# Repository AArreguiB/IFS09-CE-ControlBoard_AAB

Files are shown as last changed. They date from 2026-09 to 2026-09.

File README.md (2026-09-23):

isc-full-primary

# IFSXX-[DPT]_[PCB/PURPOSE]

Embedded firmware for the **[PCB/PURPOSE]** of the IFSXX, developed on XXXXXXXXX with XXXXXXXXX.

---

## Getting started

1. Create a GitHub account if you don't have one yet.
2. Download and install [GitHub Desktop](https://desktop.github.com/) (beginner) or [Git CLI](https://git-scm.com/book/en/v2/Getting-Started-Installing-Git) (advanced).

   - If this is your first time using GitHub Desktop, make sure to read the [User Manual](https://help.github.com/desktop/guides/).
   - If this is your first time using Git, start with a tutorial. There are many available online:
     - [Git Tutorial](https://git-scm.com/docs/gittutorial)
     - [Atlassian Git Tutorial](https://www.atlassian.com/git/tutorials/)
   - Keep a copy of [GitHub's Git Cheat Sheet](https://services.github.com/kit/downloads/github-git-cheat-sheet.pdf) handy as a reference.

3. Clone this repository to your machine (update these links!!):
   - SSH: `git@github.com:isc-fs/IFSXX-[DPT]_[PCB/PURPOSE].git`
   - HTTPS: `https://github.com/isc-fs/IFSXX-[DPT]_[PCB/PURPOSE].git`

---

## How we work with this repository

### Main branches

The repository has two permanent branches:

**`main`** is the production branch. It contains only validated code that can be flashed onto the car. Never work directly on it.

**`dev`** is the development branch. It is the integration point where everyone's work comes together. Never work directly on it either — all changes arrive through a feature branch.

```
main  ──────────────────●──────────────────────●──▶  (validated releases only)
                        ↑                      ↑
dev   ──────●───●───●───●───●───●───●───●───●──●──▶  (continuous integration)
            ↑   ↑       ↑   ↑   ↑       ↑   ↑
          feat/1 fix/1 feat/2 fix/2   feat/3 fix/3
```

### Feature branches

All work — whether a new feature or a bug fix — is done on a **feature branch** created from `dev`. When the work is ready, a Pull Request is opened toward `dev`, reviewed, merged, and the branch is deleted.

There are two branch types, each with its own independent numeric counter:

```
feat/<n>   →  new functionality  (feat/1, feat/2, feat/3 ...)
fix/<n>    →  bug fix            (fix/1,  fix/2,  fix/3  ...)
```

The `feat` and `fix` counters are independent: `feat/2` and `fix/2` can exist at the same time with no conflict.

### Tracking branch history

Feature branches are deleted after merging to keep the repository clean. The history of each branch is preserved in **GitHub Issues**.

Every branch has one associated issue. The issue carries a **label** (`feat` or `fix`) and its title includes the branch number, for example: `[feat/3] Add CAN broadcast for mission state`. When the branch is merged and deleted, the issue is closed — becoming a permanent record of all the work done.

To see which branches are currently active: filter issues by label and status `open`.
To browse the full history: filter by label and status `closed`.
The number for the next branch of each type is the last closed issue of that type plus one.

> Example: if the last closed issue with label `feat` is `[feat/4] ...`, the next feature branch will be `feat/5`.

---

## Automation

The repository includes a GitHub Actions workflow that manages tracking issues automatically. No setup is required — it works for every developer as soon as they create a branch.

### Automatic issue creation

When a `feat/*` or `fix/*` branch is pushed to GitHub, the workflow automatically opens an issue with:

- The corresponding `[feat/N]` or `[fix/N]` title
- The correct label (`feat` or `fix`)
- A template with sections for describing the work and adding notes
- The name of the developer who created the branch

### Wrong number warning

If the branch number is not the next expected one (either too low or too high), the issue will display a warning indicating the correct number and asking the developer to delete and recreate the branch with the right name.

### Auto-fill description from first commit

When the developer makes their first commit and pushes it, the workflow automatically updates the *"What does this branch do?"* section of the issue with that commit message.

- If the developer manually edits the issue before pushing their first commit, the workflow will not overwrite the description.
- The description is only updated once — subsequent commits do not modify the issue.

---

## Step-by-step workflow

### 1. Create the branch

```bash
# Make sure you are on an up-to-date dev
git checkout dev
git pull origin dev

# Create your branch using the next available number for its type
# (last closed issue of that type + 1)
git checkout -b feat/5    # or fix/3, depending on that type's counter
```

> To find the right number: go to **Issues → filter by label `feat` or `fix` → sort by newest** and read the last number.

### 2. Push the branch

```bash
git push origin feat/5
```

The tracking issue will be opened automatically on GitHub within seconds.

### 3. Work and commit

```bash
# Make your changes and commit with a clear, descriptive message
git add .
git commit -m "short description of what this commit does"

# Push the changes
git push origin feat/5
```

The message of your **first commit** will be used to automatically fill in the issue description.

### 4. Open a Pull Request

When the work is ready, open a Pull Request on GitHub from your branch toward `dev`. In the PR description write `Closes #<issue-number>` so the issue closes automatically when the PR is merged.

Before requesting a review, check that:
- The code compiles with no errors or warnings
- You have tested the change on the bench if applicable
- The PR targets `dev`, not `main`

### 5. Review and merge

Another team member will review the PR. Once approved, it is merged into `dev` and the branch is deleted. The issue will be closed as a permanent record.

### 6. Merging into main

When `dev` holds a set of validated changes that are ready for the car, a responsible team member opens a Pull Request from `dev` into `main`. This only happens after full firmware validation (HIL/bench).

---

*ISC Racing Team — IFS08 Driverless*

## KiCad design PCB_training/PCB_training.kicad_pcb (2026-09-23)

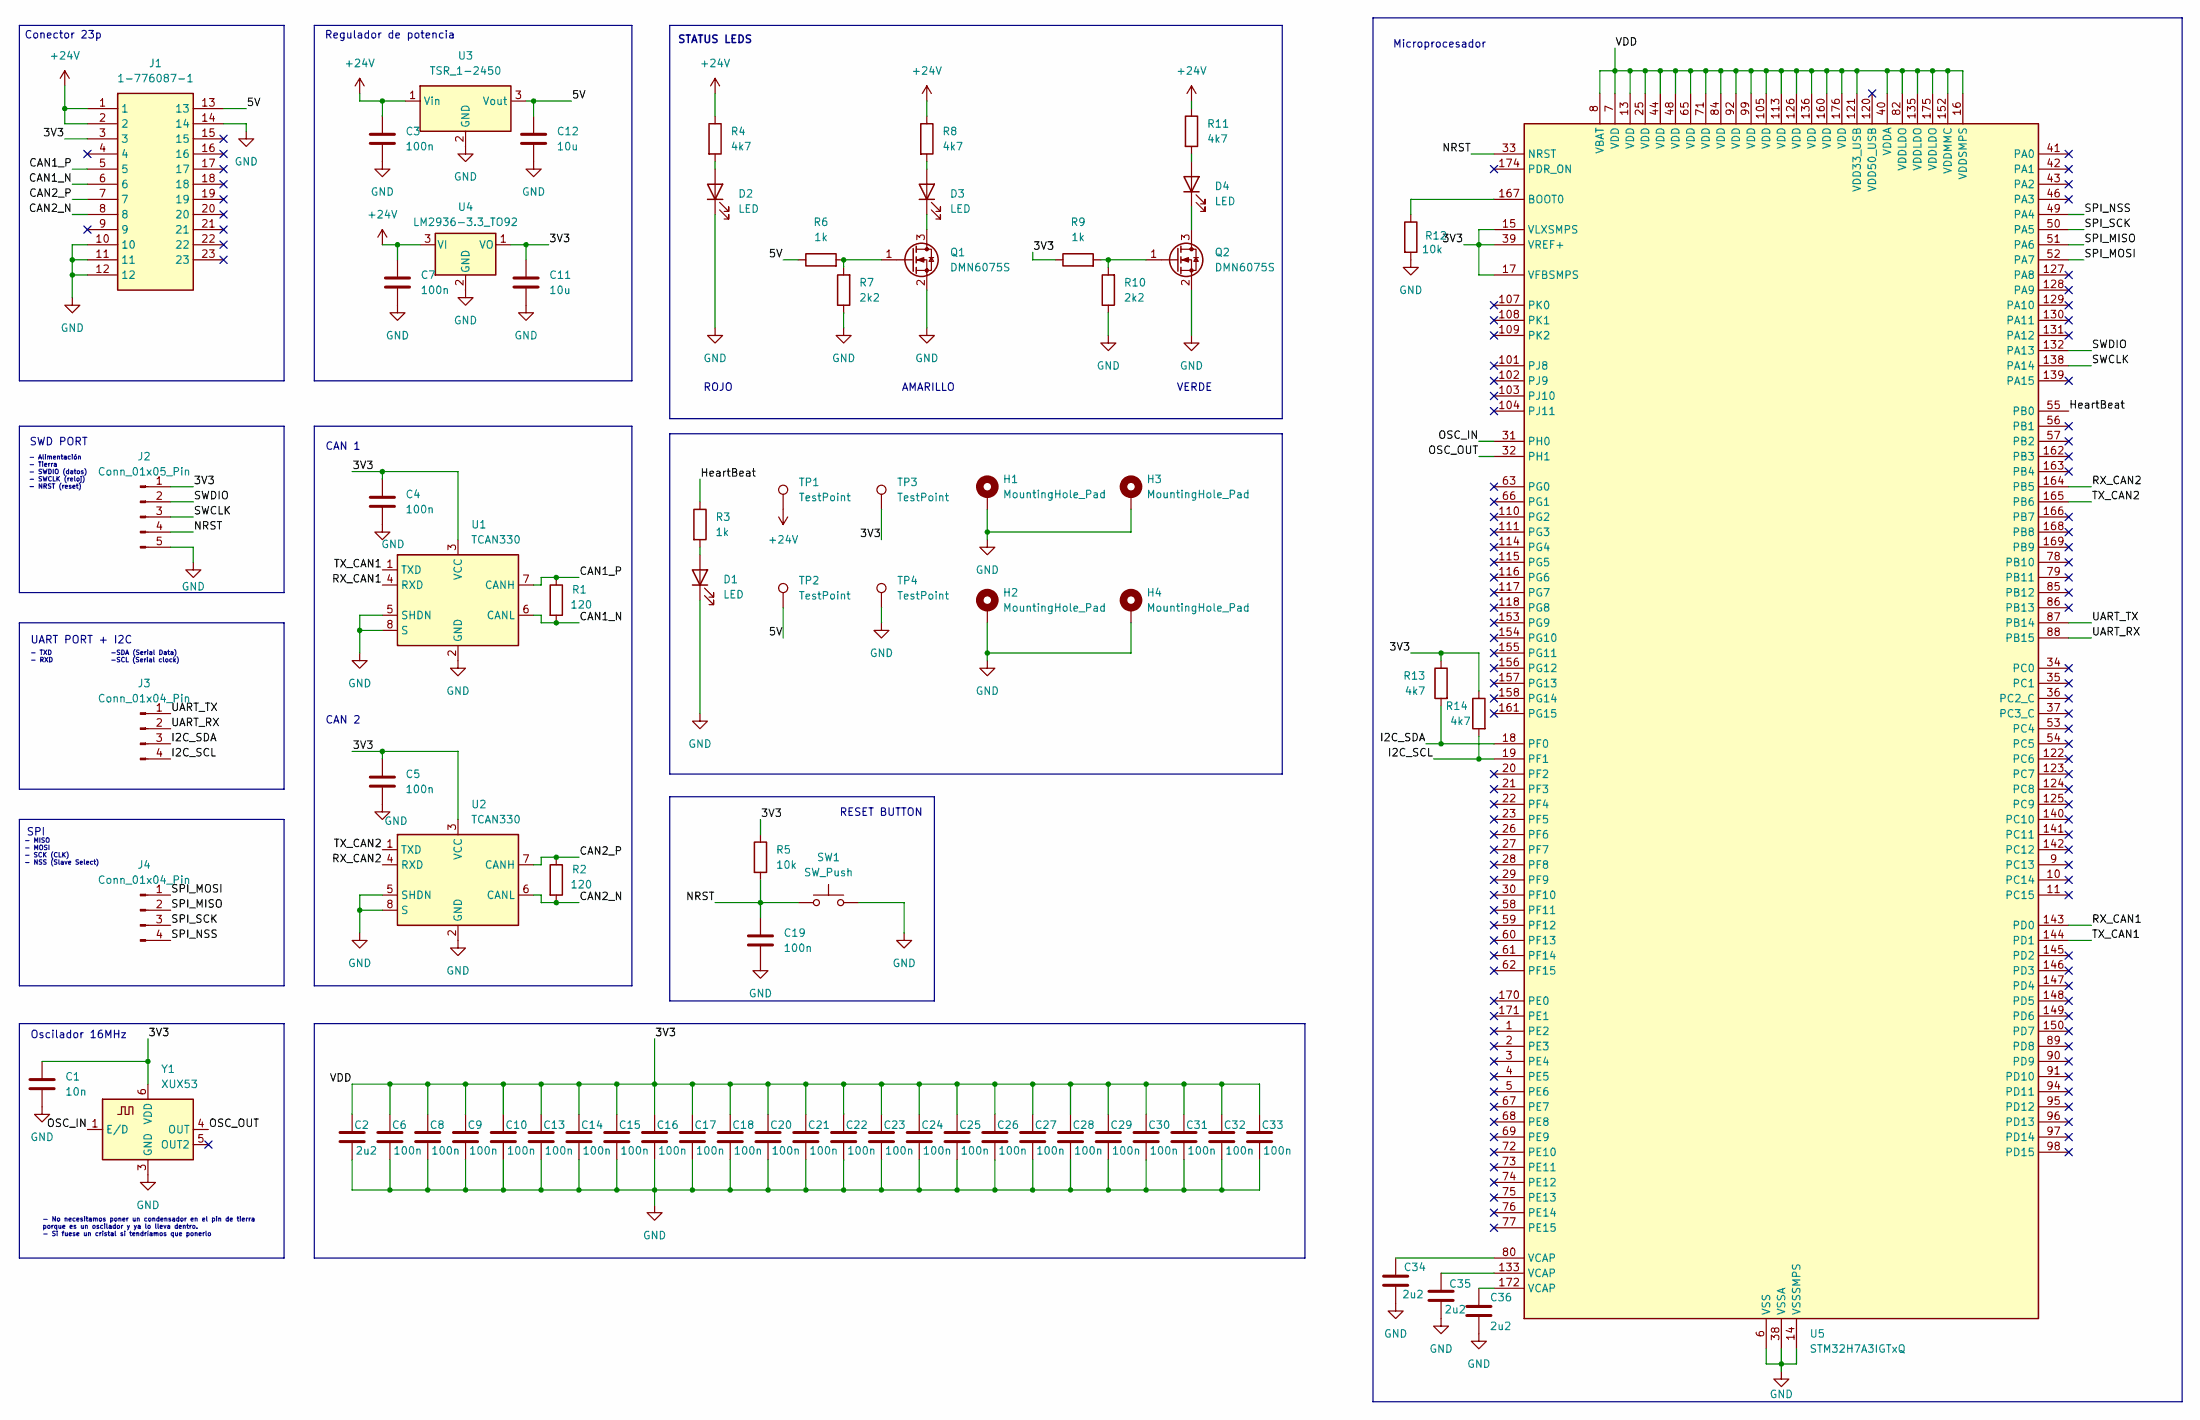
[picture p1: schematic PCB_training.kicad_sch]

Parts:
C1: 10n; C_0805_2012Metric_Pad1.18x1.45mm_HandSolder
C2, C34, C35, C36: 2u2; C_0805_2012Metric_Pad1.18x1.45mm_HandSolder
C3, C4, C5, C6, C7, C8, C9, C10, C13, C14, C15, C16, C17, C18, C19, C20, C21, C22, C23, C24, C25, C26, C27, C28, C29, C30, C31, C32, C33: 100n; C_0805_2012Metric_Pad1.18x1.45mm_HandSolder
C11, C12: 10u; C_0805_2012Metric_Pad1.18x1.45mm_HandSolder
D1, D2, D3, D4: LED; LED_1206_3216Metric_Pad1.42x1.75mm_HandSolder
H1, H2, H3, H4: MountingHole_Pad; MountingHole_3.2mm_M3_Pad
J1: 1-776087-1; 17760871; Mouser Part Number 571-1-776087-1
J2: Conn_01x05_Pin; PinHeader_1x05_P2.54mm_Vertical
J3, J4: Conn_01x04_Pin; PinHeader_1x04_P2.54mm_Vertical
Q1, Q2: DMN6075S; SOT-23
R1, R2: 120; R_0805_2012Metric_Pad1.20x1.40mm_HandSolder
R3, R6, R9: 1k; R_0805_2012Metric_Pad1.20x1.40mm_HandSolder
R4, R8, R11, R13, R14: 4k7; R_0805_2012Metric_Pad1.20x1.40mm_HandSolder
R5, R12: 10k; R_0805_2012Metric_Pad1.20x1.40mm_HandSolder
R7, R10: 2k2; R_0805_2012Metric_Pad1.20x1.40mm_HandSolder
SW1: SW_Push; Panasonic_EVQPUK_EVQPUB
TP1, TP2, TP3, TP4: TestPoint; TestPoint_Pad_D2.0mm
U1, U2: TCAN330; SOIC-8_3.9x4.9mm_P1.27mm
U3: TSR_1-2450; Converter_DCDC_TRACO_TSR-1_THT
U4: LM2936-3.3_TO92; TO-92_Inline
U5: STM32H7A3IGTxQ; LQFP-176_24x24mm_P0.5mm
Y1: XUX53; Oscillator_SMD_IDT_JS6-6_5.0x3.2mm_P1.27mm

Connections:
+24V: C3.1, C7.1, J1.1, J1.2, R4.1, R8.1, R11.1, TP1.1 (1_1), U3.1 (Vin), U4.3 (VI)
/3V3: C1.1, C2.1, C4.1, C5.1, C6.1, C8.1, C9.1, C10.1, C11.1, C13.1, C14.1, C15.1, C16.1, C17.1, C18.1, C20.1, C21.1, C22.1, C23.1, C24.1, C25.1, C26.1, C27.1, C28.1, C29.1, C30.1, C31.1, C32.1, C33.1, J1.3, J2.1, R5.1, R9.1, R13.1, R14.1, TP3.1 (1_1), U1.3 (VCC), U2.3 (VCC), U4.1 (VO), U5.7 (VDD), U5.8 (VBAT), U5.13 (VDD), U5.15 (VLXSMPS), U5.16 (VDDSMPS), U5.17 (VFBSMPS), U5.25 (VDD), U5.39 (VREF+), U5.40 (VDDA), U5.44 (VDD), U5.48 (VDD), U5.65 (VDD), U5.71 (VDD), U5.82 (VDDLDO), U5.84 (VDD), U5.92 (VDD), U5.99 (VDD), U5.105 (VDD), U5.113 (VDD), U5.121 (VDD33_USB), U5.126 (VDD), U5.135 (VDDLDO), U5.136 (VDD), U5.152 (VDDMMC), U5.160 (VDD), U5.175 (VDDLDO), U5.176 (VDD), Y1.6 (VDD)
/5V: C12.1, J1.13, R6.1, TP2.1 (1_1), U3.3 (Vout)
/CAN1_N: J1.6, R1.2, U1.6 (CANL)
/CAN1_P: J1.5, R1.1, U1.7 (CANH)
/CAN2_N: J1.8, R2.2, U2.6 (CANL)
/CAN2_P: J1.7, R2.1, U2.7 (CANH)
/HeartBeat: R3.1, U5.55 (PB0)
/I2C_SCL: J3.4, R14.2, U5.19 (PF1)
/I2C_SDA: J3.3, R13.2, U5.18 (PF0)
/NRST: C19.1, J2.4, R5.2, SW1.1, U5.33 (NRST)
/OSC_IN: U5.31 (PH0), Y1.1 (E/D)
/OSC_OUT: U5.32 (PH1), Y1.4 (OUT)
/RX_CAN1: U1.4 (RXD), U5.143 (PD0)
/RX_CAN2: U2.4 (RXD), U5.164 (PB5)
/SPI_MISO: J4.2, U5.51 (PA6)
/SPI_MOSI: J4.1, U5.52 (PA7)
/SPI_NSS: J4.4, U5.49 (PA4)
/SPI_SCK: J4.3, U5.50 (PA5)
/SWCLK: J2.3, U5.138 (PA14)
/SWDIO: J2.2, U5.132 (PA13)
/TX_CAN1: U1.1 (TXD), U5.144 (PD1)
/TX_CAN2: U2.1 (TXD), U5.165 (PB6)
/UART_RX: J3.2, U5.88 (PB15)
/UART_TX: J3.1, U5.87 (PB14)
GND: C1.2, C2.2, C3.2, C4.2, C5.2, C6.2, C7.2, C8.2, C9.2, C10.2, C11.2, C12.2, C13.2, C14.2, C15.2, C16.2, C17.2, C18.2, C19.2, C20.2, C21.2, C22.2, C23.2, C24.2, C25.2, C26.2, C27.2, C28.2, C29.2, C30.2, C31.2, C32.2, C33.2, C34.2, C35.2, C36.2, D1.1 (K), D2.1 (K), H1.1 (1_1), H2.1 (1_1), H3.1 (1_1), H4.1 (1_1), J1.10, J1.11, J1.12, J1.14, J2.5, Q1.2 (S), Q2.2 (S), R7.1, R10.1, R12.2, SW1.2, TP4.1 (1_1), U1.2 (GND), U1.5 (SHDN), U1.8 (S), U2.2 (GND), U2.5 (SHDN), U2.8 (S), U3.2 (GND), U4.2 (GND), U5.6 (VSS), U5.12 (VSS), U5.14 (VSSSMPS), U5.24 (VSS), U5.38 (VSSA), U5.45 (VSS), U5.47 (VSS), U5.64 (VSS), U5.70 (VSS), U5.81 (VSS), U5.83 (VSS), U5.93 (VSS), U5.100 (VSS), U5.106 (VSS), U5.112 (VSS), U5.119 (VSS), U5.134 (VSS), U5.137 (VSS), U5.151 (VSS), U5.159 (VSS), U5.173 (VSS), Y1.3 (GND)
unnamed: C34.1, U5.80 (VCAP)
unnamed: C35.1, U5.133 (VCAP)
unnamed: C36.1, U5.172 (VCAP)
unnamed: D1.2 (A), R3.2
unnamed: D2.2 (A), R4.2
unnamed: D3.2 (A), R8.2
unnamed: D3.1 (K), Q1.3 (D)
unnamed: D4.2 (A), R11.2
unnamed: D4.1 (K), Q2.3 (D)
unnamed: Q1.1 (G), R6.2, R7.2
unnamed: Q2.1 (G), R9.2, R10.2
unnamed: R12.1, U5.167 (BOOT0)

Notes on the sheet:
Conector 23p
SWD PORT
- TXD - RXD
- Alimentación - Tierra - SWDIO (datos) - SWCLK (reloj) - NRST (reset)
Microprocesador
- MISO - MOSI - SCK (CLK) - NSS (Slave Select)
SPI
ROJO
RESET BUTTON
AMARILLO
-SDA (Serial Data) -SCL (Serial clock)
Oscilador 16MHz
VERDE
Regulador de potencia
CAN 1
UART PORT + I2C
- No necesitamos poner un condensador en el pin de tierra porque es un oscilador y ya lo lleva dentro. - Si fuese un cristal si tendríamos que ponerlo
STATUS LEDS
CAN 2

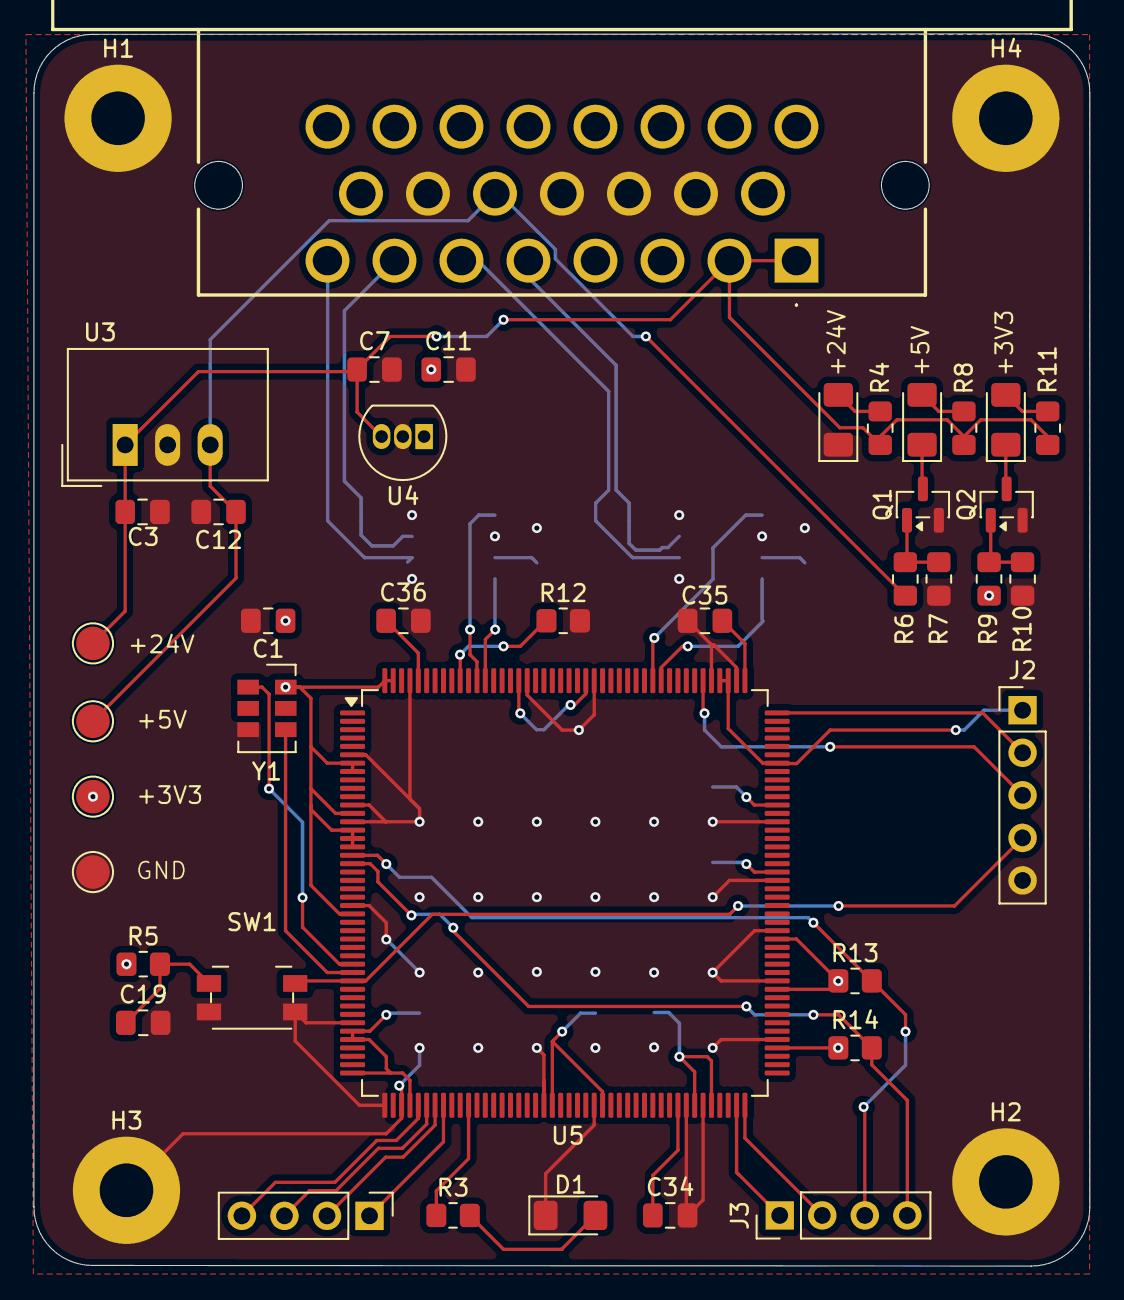
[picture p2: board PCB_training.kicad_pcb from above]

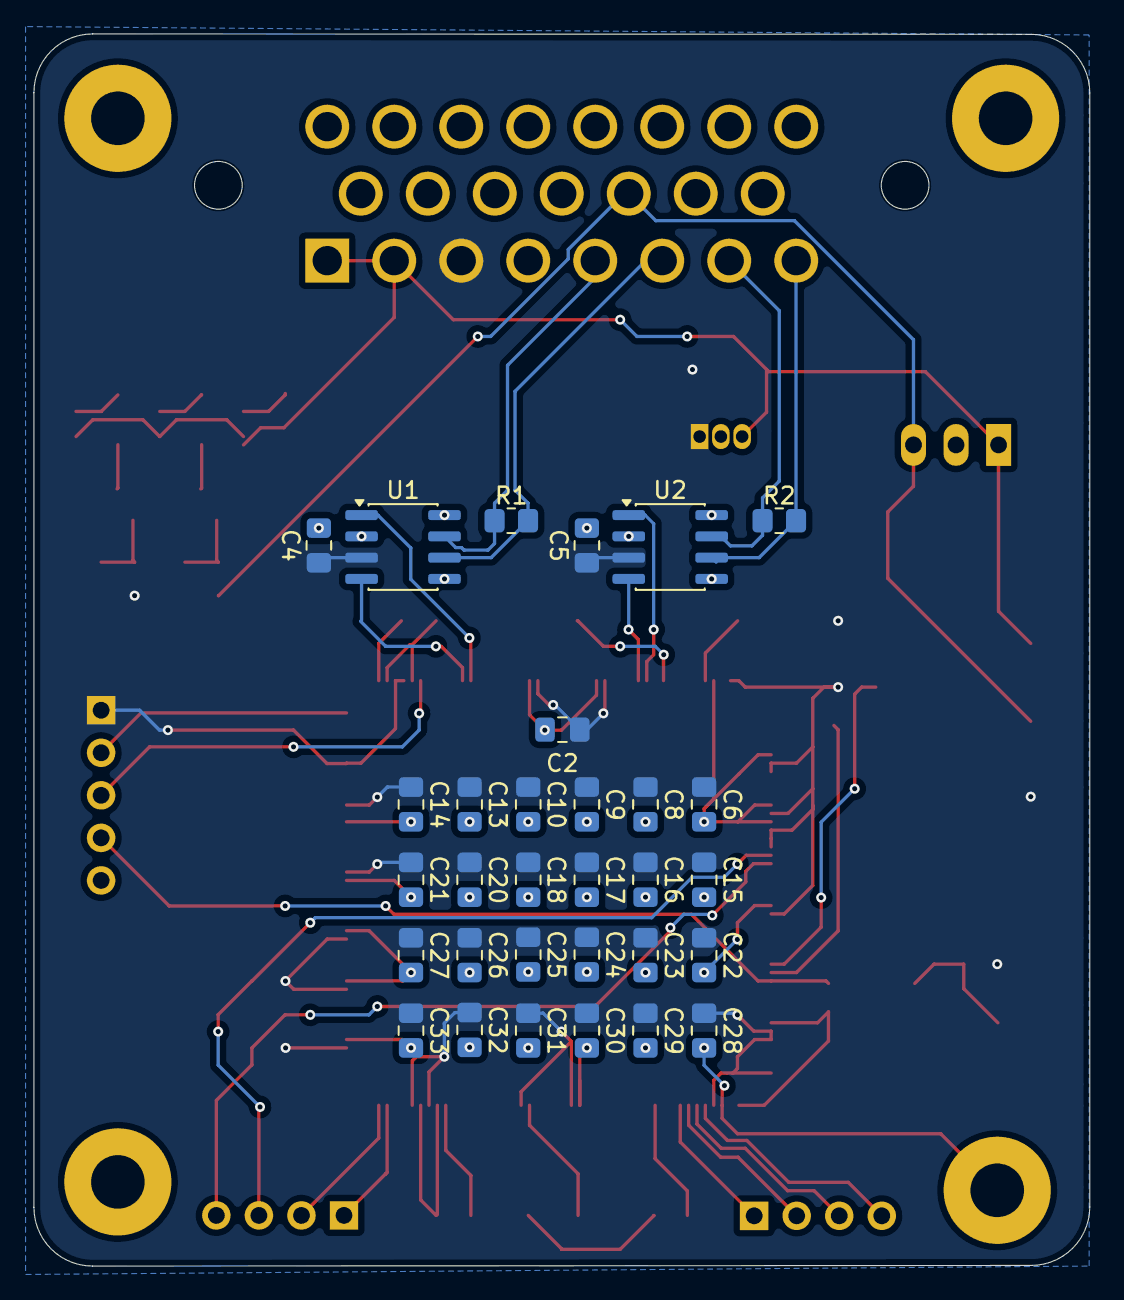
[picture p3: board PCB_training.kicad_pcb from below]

Board: 2 copper layers, 63.0 x 73.6 mm, 75 parts (31 on the bottom side), 38 nets.
